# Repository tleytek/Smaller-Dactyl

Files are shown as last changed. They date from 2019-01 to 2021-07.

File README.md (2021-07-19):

# Smaller-Dactyl

This is a fork of the [Dactyl-Manuform-Mini](https://github.com/l4u/dactyl-manuform-mini-keyboard). The Dactyl-ManuForm-Mini is a fork of the [Dactyl-Manuform](https://github.com/tshort/dactyl-keyboard). The Dactyl-Manuform is a fork of the [Dactyl](https://github.com/adereth/dactyl-keyboard) with the thumb cluster from [ManuForm](https://github.com/jeffgran/ManuForm).

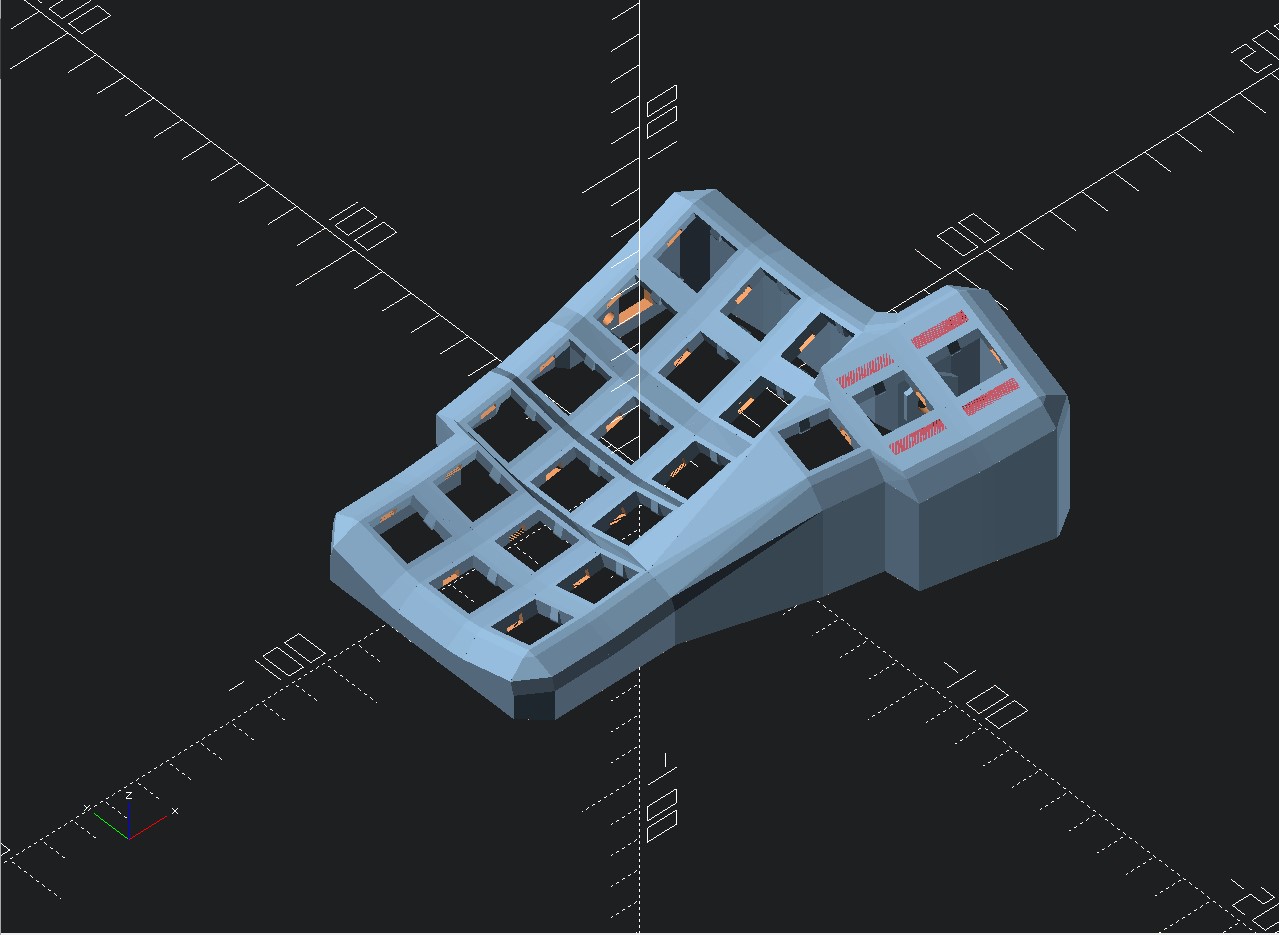
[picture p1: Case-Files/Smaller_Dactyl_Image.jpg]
Dactyl variant


## Info/The Why

So I built a dactyl manuform and dactyl-manuform mini before I built a Dactyl. The problems I had with the manuform variants were the thumb cluster locations. The manuform had a downward/convex curve to its thumb cluster, where as the dactyl is a concave thumb cluster curve. So I built a Dactyl and loved the thumb cluster placement alot more, but the finger columns were not inline with my fingers, so my fingers weren't sitting on my home row keys when neutral like they were on the manuform variants. Modifiying the column placements was really hard for me on the Dactyl source code because the case would break when moving the column coordinates, leaving holes and weird artifacts. As someone with no OpenSCAD or Clojure experience, the dactyl-manuform was much easier to understand and modify than the Dactyl. So I tried to make the dactyl-manuform into a dactyl by taking the thumb cluster from [Matt Adereth's](https://github.com/adereth/) source code. What I like about the dactyl-manuform variant l4u made is that its closer to the ground, has better I/O made, and it still has tshorts easy to use column adjustments that won't break the case like the original dactyls code. Since I haven't got around to wiring up a dactyl, I have been using the next closest thing, or I should say the origin, the kinesis advantage with the stapelberg mod for added qmk functionality.

## Features created by [l4u](https://github.com/l4u/dactyl-manuform-mini-keyboard)

- The use of sidenubs can be disabled. Sidenub should be disabled if you use Kailh, and Outemu. If you use Cherry MX, Gateron or Zealios switches, you can enable the sidenubs.
- Spaces for rentention tabs are added.
- One key in the thumb cluster has been removed. Other thumb keys are also adjusted.
- The total height is reduced and wire posts are removed. This results in a
  higher printing speed and a lower cost.
- A TRRS mount instead of a RJ9 mount is used.
- A micro USB mount is used. A breakout board, or an extension cable can be used.
- Screw posts are moved inside. The holes are designed for TRISERT® thread inserts 145m3.
- The pro micro holder has been modified. Dupont cables can be used.

## Getting Started

If you'd like to challenge yourself and make one of these then head over to the [Case Files](https://github.com/tleytek/Smaller-Dactyl/tree/master/Case%20Files)

## License

Copyright © 2015-2018 Matthew Adereth, Tom Short and Leo Lou

The source code for generating the models is distributed under the [GNU AFFERO GENERAL PUBLIC LICENSE Version 3](LICENSE).

The generated models are distributed under the [Creative Commons Attribution-ShareAlike 4.0 International (CC BY-SA 4.0)](LICENSE-models).

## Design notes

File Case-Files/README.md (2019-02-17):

## Getting the case and bottom plate

### Option 1: Generate OpenSCAD and STL models

- Navigate to the dactyl-keyboard folder in CMD
- Run `lein generate` or `lein auto generate`
- This will regenerate the `things/*.scad` files
- Use OpenSCAD to open a `.scad` file.
- When done, render the file and export as an STL file.

### Option 2: Download from Thingiverse

### The bottom plate

Generating the bottom plate is tricky as I haven't figured out a way to get the shape to cover the entire hole as well as the perimeter of the bottom. I have files made to print for the bottom, but when you make adjustments to your print the bottom plate will no longer align and if you decide to close the bottom up, it will not be flush with the perimeter of the print and may have small gaps.

## Parts

- Soldering Iron - This is up to you, I use the TS100 soldering iron
- Solder - https://www.amazon.ca/dp/B07H8Z2D7B/ref=sspa_dk_hqp_detail_aax_0?psc=1
- 24 AWG Enameled Copper Wire - https://www.amazon.ca/gp/product/B007OYG9HS/ref=oh_aui_search_asin_title?ie=UTF8&psc=1
- Fume Extractor (Optional, an argument can be made that these low budget fume extractors don't work well but I use one and I love it) - https://www.amazon.ca/Kulannder-Adjustable-Extractor-Soldering-Eliminate/dp/B077Q99PPV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
- Left and right Smaller-Dactyl case - (Thingiverse link)
- Enough switches to fill your case - https://novelkeys.xyz/collections/switches
- Digi key BOM - https://www.digikey.ca/BOM/Create/CreateSharedBom?bomId=7771467
- 2 Pro-Micros* - https://www.amazon.ca/XCSOURCE-ATMEGA32U4-Arduino-Leonardo-TE463/dp/B01F78T2FS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
- Wrist Prints - thingiverse link
- Kinesis Advantage Palm Pads (Optional) - https://kinesis-ergo.com/shop/advantage-palm-pads-black/

*There is a Pro-Micro on amazon that is cheaper and has prime from a brand called KEYESTUDIO, but I have had issues with entering DFU mode using QMK software on their product, where as the XCSource pro-micros were able to perform without issue. This is an important factor if you decide to close up the bottom, which is instructed in this guide, because when you wish to flash the chip to make changes to your keymap, you must enter DFU mode. The only other way of doing so on KEYESTUDIO Pro-Micros is through hardware, requiring you to press the reset button on the pro-micro, or shorting the reset and ground pins.

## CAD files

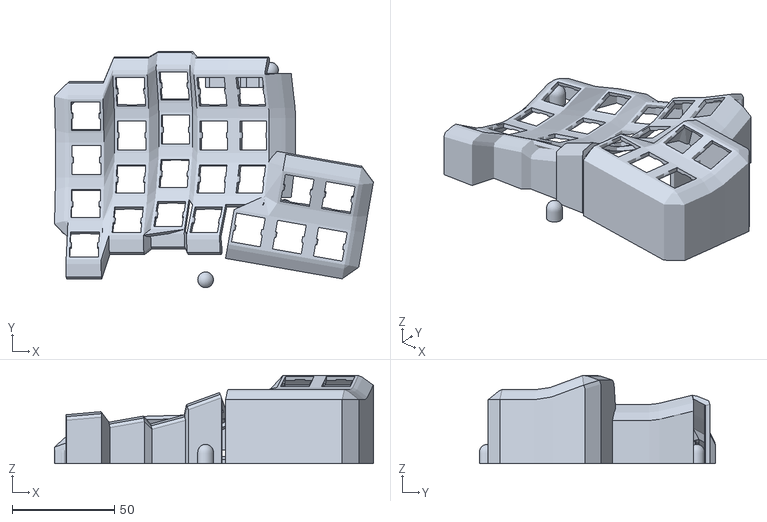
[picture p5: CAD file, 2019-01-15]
Case-Files/test/left.stl
155.7 x 115.3 x 43.0

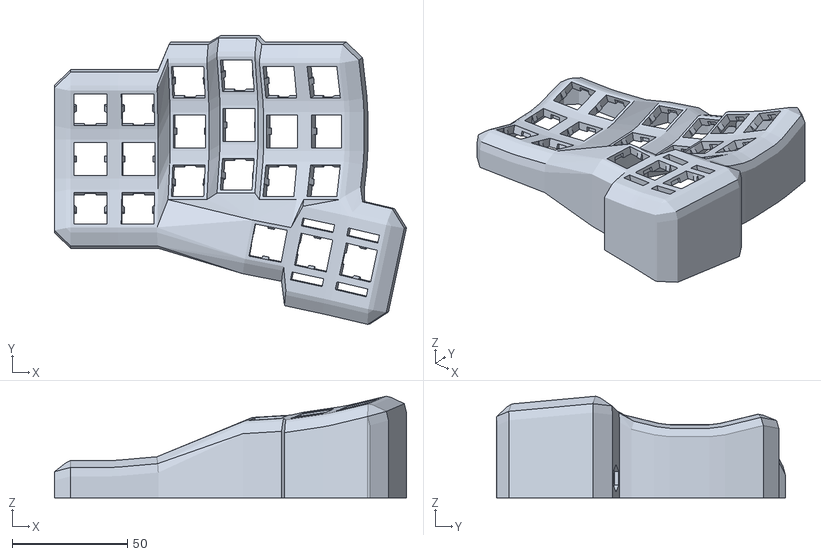
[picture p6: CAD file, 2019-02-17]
Case-Files/things/left.stl
152.9 x 125.5 x 44.2

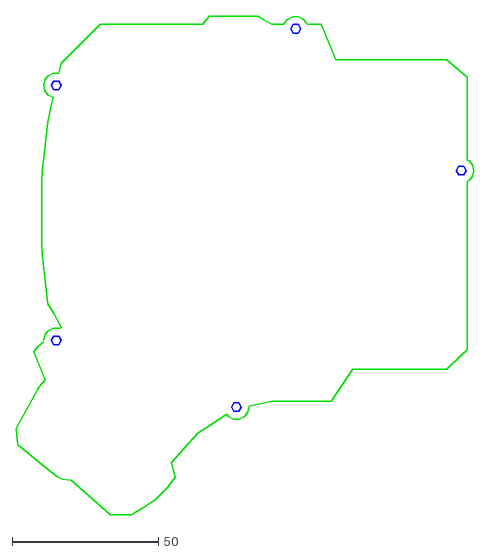
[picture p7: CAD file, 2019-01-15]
Case-Files/things/plates/right-5x6-plate-ready-to-cut.dxf
156.5 x 170.5

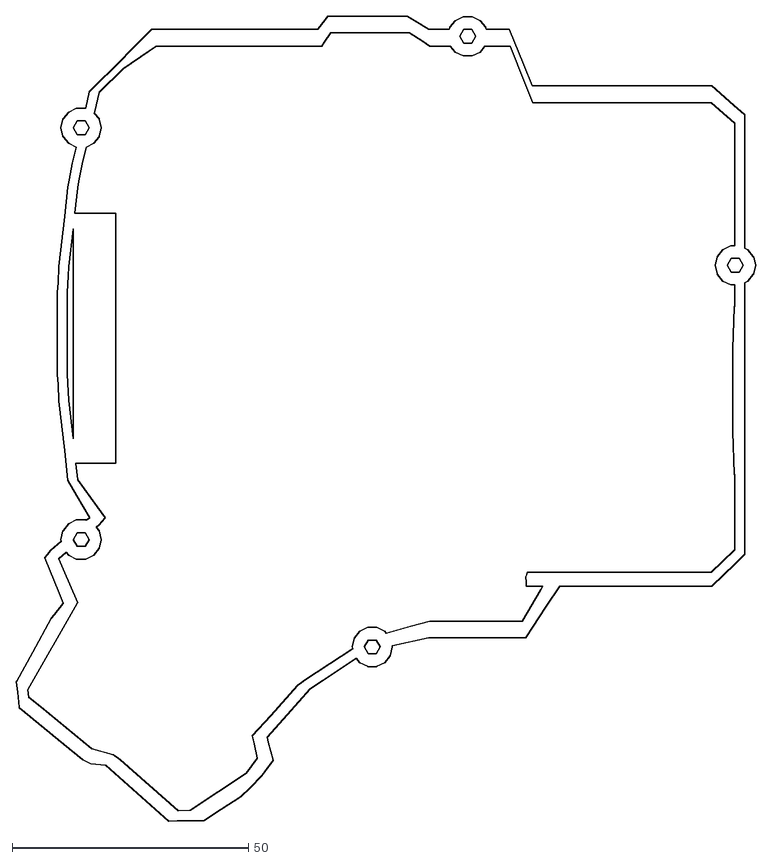
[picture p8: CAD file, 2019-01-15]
Case-Files/things/plates/right-5x6-plate.dxf
156.5 x 170.5

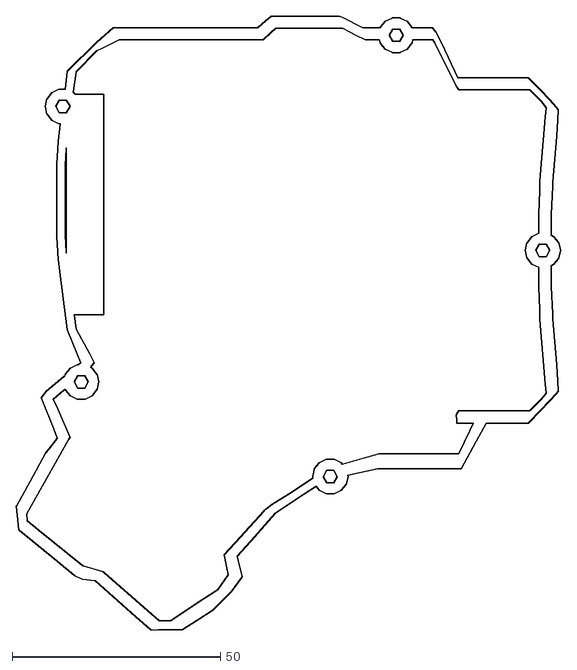
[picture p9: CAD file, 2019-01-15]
Case-Files/things/plates/right-4x5-plate.dxf
130.7 x 147.5

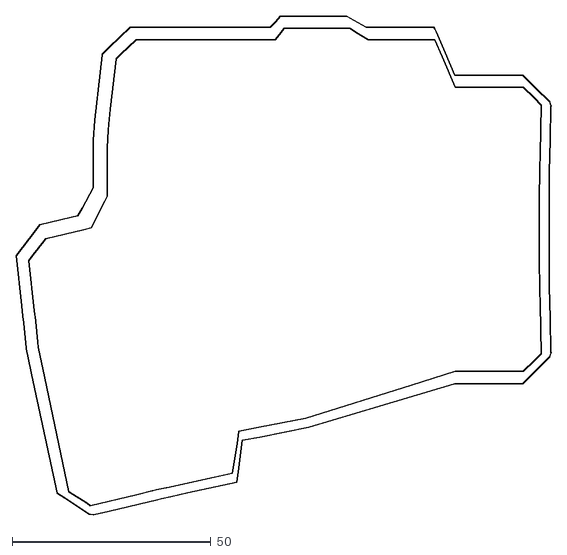
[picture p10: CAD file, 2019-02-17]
Case-Files/things/right-plate.dxf
134.6 x 125.5

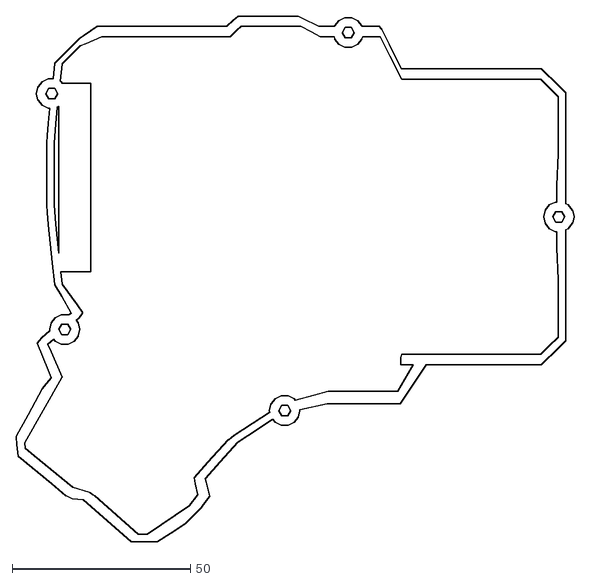
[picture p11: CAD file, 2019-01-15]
Case-Files/things/plates/right-4x6-plate.dxf
156.5 x 147.5

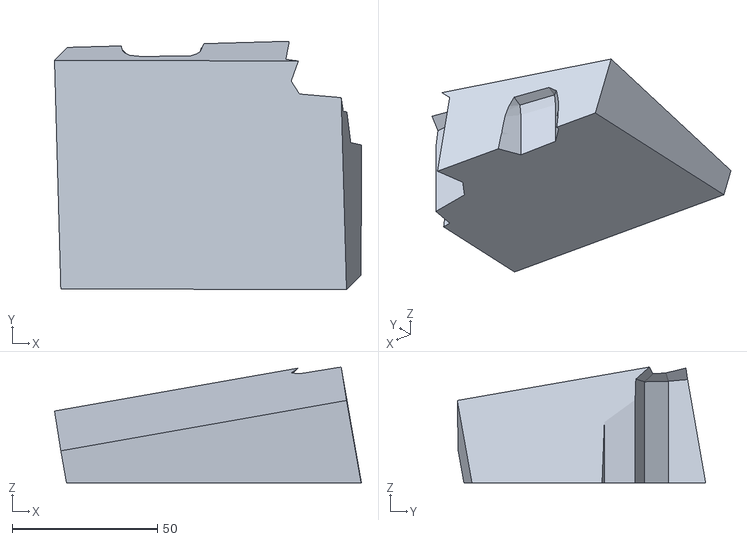
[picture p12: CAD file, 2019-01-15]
Case-Files/things/wristrestv2.stl
105.8 x 85.6 x 40.0

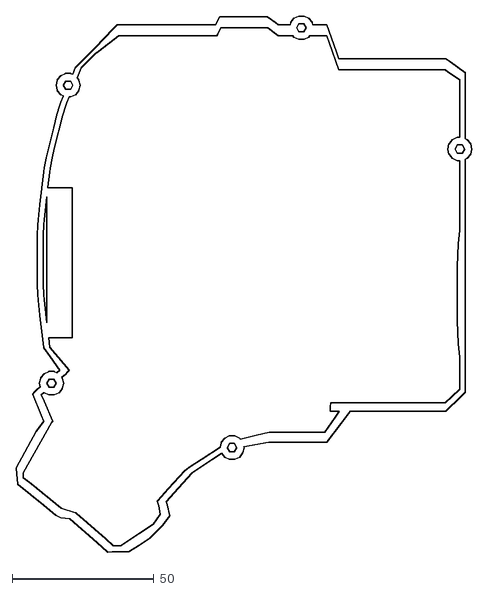
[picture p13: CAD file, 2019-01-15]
Case-Files/things/plates/right-6x6-plate.dxf
160.9 x 189.3

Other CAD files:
Case-Files/things/right.stl
Case-Files/things/left.scad
Case-Files/things/right-plate.scad
Case-Files/things/right.scad
Case-Files/things/plates/right-plate.scad
Case-Files/test/left.scad
Case-Files/things/plates/right-test.scad
Case-Files/things/plates/test.scad
Case-Files/things/right-test.scad
Case-Files/things/test.scad

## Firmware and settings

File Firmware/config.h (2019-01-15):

/*
Copyright 2012 Jun Wako <wakojun@gmail.com>
Copyright 2015 Jack Humbert

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
You should have received a copy of the GNU General Public License
along with this program.  If not, see <http://www.gnu.org/licenses/>.
*/

#pragma once

#include "config_common.h"

/* USB Device descriptor parameter */
#define VENDOR_ID       0xFEED
#define PRODUCT_ID      0x3060
#define DEVICE_VER      0x0001
#define MANUFACTURER    Mint
// defined in subfolder
#define DESCRIPTION     I wanted a smaller dactyl

/* mouse config */
#define MOUSEKEY_INTERVAL       20
#define MOUSEKEY_DELAY          0
#define MOUSEKEY_TIME_TO_MAX    60
#define MOUSEKEY_MAX_SPEED      7
#define MOUSEKEY_WHEEL_DELAY 0

/* Set 0 if debouncing isn't needed */
#define DEBOUNCING_DELAY 5

/* serial.c configuration for split keyboard */
#define SOFT_SERIAL_PIN D0

/* Mechanical locking support. Use KC_LCAP, KC_LNUM or KC_LSCR instead in keymap */
#define LOCKING_SUPPORT_ENABLE
/* Locking resynchronize hack */
#define LOCKING_RESYNC_ENABLE

/* key combination for command */
#define IS_COMMAND() ( \
    keyboard_report->mods == (MOD_BIT(KC_LSHIFT) | MOD_BIT(KC_RSHIFT)) \
)

/* Enables This makes it easier for fast typists to use dual-function keys */
#define PERMISSIVE_HOLD

/* ws2812 RGB LED */
#define RGB_DI_PIN D3

#define RGBLED_NUM 12    // Number of LEDs


/*
 * Feature disable options
 *  These options are also useful to firmware size reduction.
 */

/* disable debug print */
// #define NO_DEBUG

/* disable print */
// #define NO_PRINT

/* disable action features */
//#define NO_ACTION_LAYER
//#define NO_ACTION_TAPPING
//#define NO_ACTION_ONESHOT
//#define NO_ACTION_MACRO
//#define NO_ACTION_FUNCTION

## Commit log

2019-01-15 Additions to a fork don't count as contributions v.v
    [left.scad, left.stl, right-4x5-plate.dxf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]
2019-01-18 changed headers, fixed layout issues
    [config.h]
2019-01-21 Case is more 3d print friendly
    [left.scad, left.stl, right-plate.scad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]
2019-01-24 rev 1 ready for print
    [left.scad, left.stl, right-test.scad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]
2019-02-17 Project on hiatus, kinesis is working well enough that using time to build a similar product is not worth it anymore
    [left.scad, left.stl, right-4x5-plate.dxf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]

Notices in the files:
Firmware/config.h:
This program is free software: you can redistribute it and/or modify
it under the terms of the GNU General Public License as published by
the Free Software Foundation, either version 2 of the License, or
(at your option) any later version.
